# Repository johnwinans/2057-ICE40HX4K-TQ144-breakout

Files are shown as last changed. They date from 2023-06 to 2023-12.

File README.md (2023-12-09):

# 2057-ICE40HX4K-TQ144-breakout
Minimal Raspberry PI breakout board for ICE40HX4K FPGA

Rev 3.0 has been built!
All features except for the SD card have been tested and are working properly. (Stay tuned for SD card test results).

Example test programs can be found in the [verilog](./verilog) directory.

The BOM (Bill Of Materials) can be found in [2057-ICE40HX4K-TQ144-breakout.md](./2057-ICE40HX4K-TQ144-breakout.md).

## See The Following Repos For Installing Development Tools and Example Code

- [YouTube Playlist](https://www.youtube.com/playlist?list=PL3by7evD3F52On-ws9pcdQuEL-rYbNNFB) discussing Verilog & using this breakout board
- [Raspberry PI Setup](https://github.com/johnwinans/raspberry-pi-install)
- [Icarus Setup & Example Programs](https://github.com/johnwinans/IceStick-Examples-Icarus) (For simulation and debugging)
- [More Example Programs](https://github.com/johnwinans/Verilog-Examples) (More example programs)

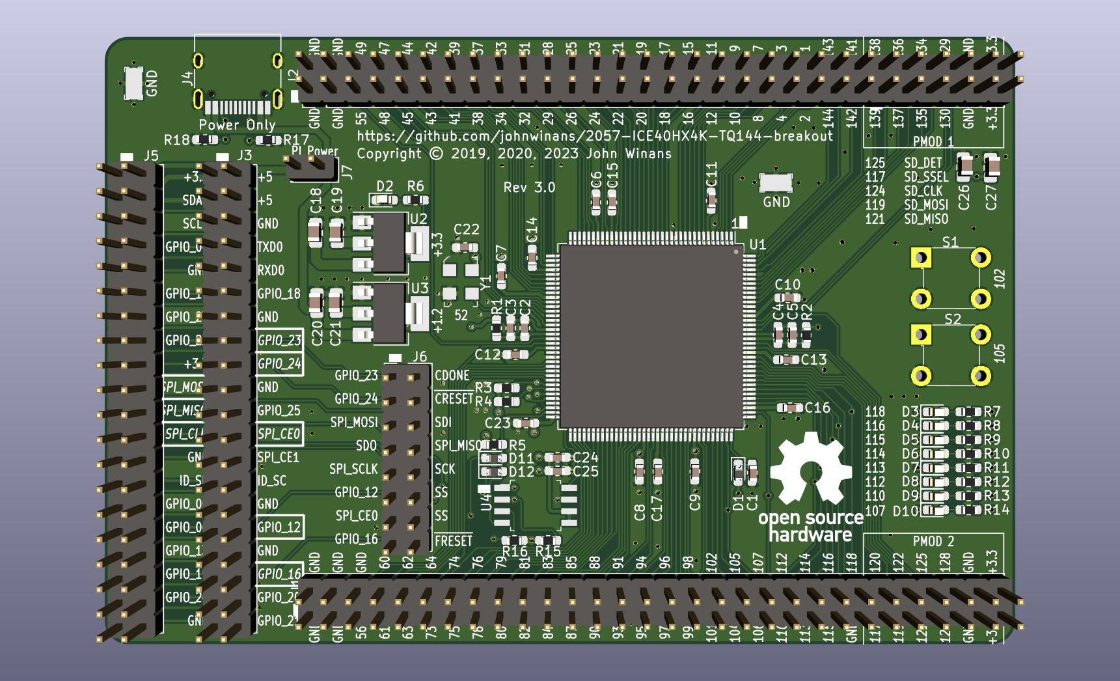
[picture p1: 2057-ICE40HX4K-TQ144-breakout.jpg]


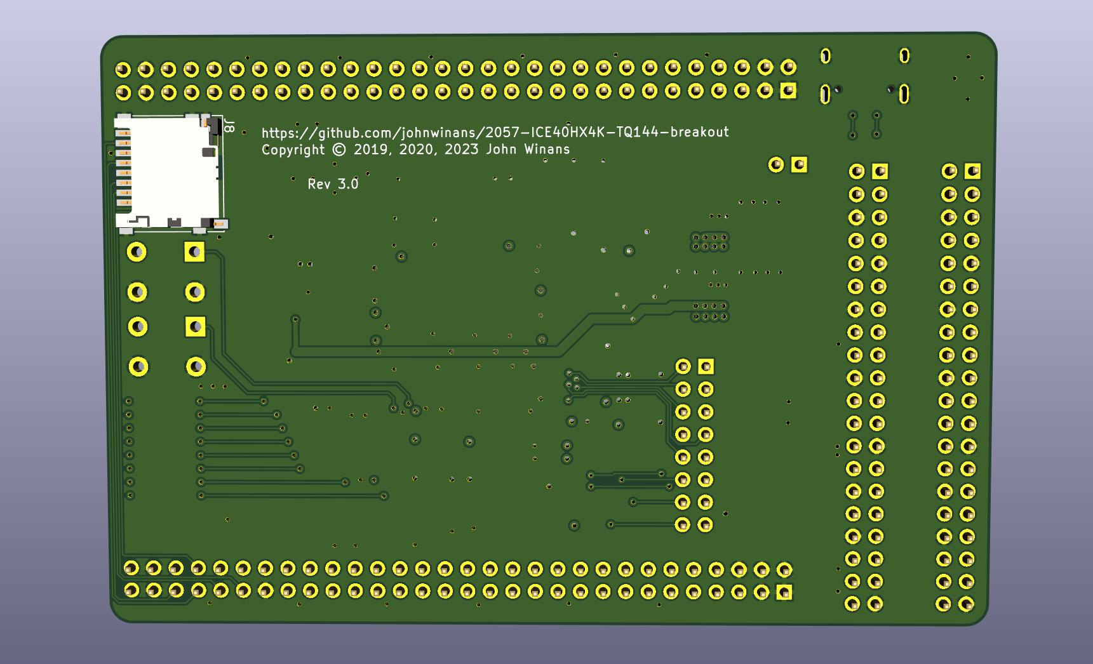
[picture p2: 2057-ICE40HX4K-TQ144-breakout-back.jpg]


# iCE40 Docs

Family page:

- iCE40 Family [page](https://www.latticesemi.com/iCE40)

Direct links to my favorite documents:

- iCE40 LP/HX Datasheet [pdf](https://www.latticesemi.com/view_document?document_id=49312)
- iCE40 Programming and Configuration Techincal Note TN1248 [pdf](https://www.latticesemi.com/view_document?document_id=46502)
- iCE40 sysCLOCK PLL Design and User Guide [pdf](https://www.latticesemi.com/view_document?document_id=47778)
- Memory Usage Guide for iCE40 Devices [pdf](https://www.latticesemi.com/view_document?document_id=47775)
- It looks like updated versions of various manuals appear here: https://www.latticesemi.com/Products/FPGAandCPLD/iCE40

# Release Notes

## Rev 1.1
- Board has been tested and is working properly.

## Rev 2.0
- Added a boot FLASH
- Added SD card

## Rev 3.0
- Change to use USB C connector for power
- Change SD card signals to connect to J1 (instead of J2)
- Change push buttons to use J1 (instead of J2)

# Alternate Parts

Substitutions for U4 (the FLASH chip) include:
- Digikey #1265-1035-1-ND AT45DB161E-SHD-T
- Digikey #1265-1041-1-ND AT45DB161E-SHD2B-T

If you substitute the FLASH then see the comments regarding setting the total number of bytes to program circa line 150 in: [verilog/prog-flash.sh](verilog/prog-flash.sh)

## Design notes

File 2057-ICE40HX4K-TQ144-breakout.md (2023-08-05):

# 2057-ICE40HX4K-TQ144-breakout.sch

## Sat Aug  5 02:54:05 2023

## Eeschema 5.1.5+dfsg1-2build2

## Component Count:73

Ref | Qty | Value | Digikey | Datasheet | Description
----|-----|-------|---------|-----------|------------
C1, C2, C4, C6, C7, C8, C9, C10, C11, C12, C13, C14, C15, C16, C17, C22, C23, C24 | 18 | .1uF | 445-1314-1-ND | https://product.tdk.com/system/files/dam/doc/product/capacitor/ceramic/mlcc/catalog/mlcc_commercial_general_en.pdf | Unpolarized capacitor
C3, C5 | 2 | 10uF | 1276-1119-1-ND | https://media.digikey.com/pdf/Data%20Sheets/Samsung%20PDFs/CL10A106MQ8NNNC_Spec.pdf | Unpolarized capacitor
C18, C20 | 2 | 10uF | 1276-1119-1-ND | https://media.digikey.com/pdf/Data%20Sheets/Samsung%20PDFs/CL10A106MQ8NNNC_Spec.pdf | Unpolarized capacitor
C19, C21, C27 | 3 | 22uF | 1276-2868-1-ND | https://media.digikey.com/pdf/Data%20Sheets/Samsung%20PDFs/CL10A226MQ8NRNE_Spec.pdf | Unpolarized capacitor, small symbol
C25 | 1 | 4.7uF | 1276-1045-1-ND | https://media.digikey.com/pdf/Data%20Sheets/Samsung%20PDFs/CL10A475KQ8NNNC_Spec.pdf | Unpolarized capacitor
C26 | 1 | .1uF | 445-1314-1-ND | https://product.tdk.com/system/files/dam/doc/product/capacitor/ceramic/mlcc/catalog/mlcc_commercial_general_en.pdf | Unpolarized capacitor, small symbol
D1, D11, D12 | 3 | 1N4448WSF-7 | 1N4448WSF-7DICT-ND | https://www.diodes.com/assets/Datasheets/1N4448WSF.pdf | Diode, filled shape
D2, D3, D4, D5, D6, D7, D8, D9, D10 | 9 | LED_ALT | B1911PG--20D000514U1930 | https://media.digikey.com/pdf/Data%20Sheets/Harvatek%20PDFs/B1911PG--20D000514U1930.pdf | Light emitting diode, filled shape
J1, J2 | 2 | Conn_02x30_Odd_Even | S2011EC-30-ND | https://drawings-pdf.s3.amazonaws.com/11636.pdf | Generic connector, double row, 02x30, odd/even pin numbering scheme (row 1 odd numbers, row 2 even numbers), script generated (kicad-library-utils/schlib/autogen/connector/)
J3, J5 | 2 | RaspberryPI-B+header | S2011EC-20-ND | https://drawings-pdf.s3.amazonaws.com/11636.pdf | Raspberry PI J8 GPIO header
J4 | 1 | USB4105-GF-A | 2073-USB4105-GF-ATR-ND | https://media.digikey.com/pdf/Data%20Sheets/GCT%20PDFs/USB4105%20-%20Product%20Drawing.pdf | CONN RCP USB2.0 TYP C 24P SMD RA
J6 | 1 | Conn_02x08_Odd_Even | 10129381-916001BLF-ND | https://cdn.amphenol-cs.com/media/wysiwyg/files/drawing/10129381.pdf | Generic connector, double row, 02x08, odd/even pin numbering scheme (row 1 odd numbers, row 2 even numbers), script generated (kicad-library-utils/schlib/autogen/connector/)
J7 | 1 | Conn_02x01 | 2057-PH1-02-UA-ND | https://app.adam-tech.com/products/download/data_sheet/201605/ph1-xx-ua-data-sheet.pdf | Generic connector, double row, 02x01, this symbol is compatible with counter-clockwise, top-bottom and odd-even numbering schemes., script generated (kicad-library-utils/schlib/autogen/connector/)
J8 | 1 | Micro_SD_Card_Det | HR1941CT-ND | https://www.hirose.com/product/document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 | Micro SD Card Socket with card detection pins
LOGO1 | 1 | Logo_Open_Hardware_Small |  | ~ | Open Hardware logo, small
R1, R2 | 2 | 100 | 311-100HRCT-ND | https://www.yageo.com/upload/media/product/productsearch/datasheet/rchip/PYu-RC_Group_51_RoHS_L_12.pdf | Resistor
R3, R4, R5, R15, R16 | 5 | 10K | 311-10.0KHRCT-ND | https://www.yageo.com/upload/media/product/productsearch/datasheet/rchip/PYu-RC_Group_51_RoHS_L_12.pdf | Resistor
R6, R7, R8, R9, R10, R11, R12, R13, R14 | 9 | 330 | 311-330HRCT-ND | https://www.yageo.com/upload/media/product/productsearch/datasheet/rchip/PYu-RC_Group_51_RoHS_L_12.pdf | Resistor
R17, R18 | 2 | 5.1K | CR0603-FX-5101ELFCT-ND | https://www.bourns.com/docs/product-datasheets/cr.pdf?sfvrsn=574d41f6_14 | Resistor
S1, S2 | 2 | 1825910-6 | 450-1650-ND | https://www.te.com/commerce/DocumentDelivery/DDEController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 | SWITCH TACTILE SPST-NO 0.05A 24V
U1 | 1 | ICE40HX4K-TQ144 | 220-1572-ND | http://www.latticesemi.com/Products/FPGAandCPLD/iCE40 | iCE40 HX FPGA, 3520 LUTs, 1.2V, TQFP-144
U2 | 1 | AZ1117CH-3.3TRG1 | AZ1117CH-3.3TRG1DICT-ND | https://www.diodes.com/assets/Datasheets/AZ1117.pdf | 1A 20V Fixed LDO Linear Regulator, 3.3V, SOT-89/SOT-223/TO-220/TO-252/TO-263
U3 | 1 | AZ1117CH-1.2 | AZ1117CH-1.2TRG1DICT-ND | https://www.diodes.com/assets/Datasheets/AZ1117.pdf | 1A 20V Fixed LDO Linear Regulator, 3.3V, SOT-89/SOT-223/TO-220/TO-252/TO-263
U4 | 1 | AT45DB081E | 1265-1092-1-ND | https://www.renesas.com/us/en/document/dst/at45db081e-datasheet?language=en | 
Y1 | 1 | XLH536025_000000I | 631-1156-1-ND | https://www.idt.com/document/dst/xl-family-low-phase-noise-quartz-based-pll-oscillators-datasheet | XTAL OSC XO 25.0000MHZ HCMOS SMD

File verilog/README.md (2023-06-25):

# Test Apps

These instructions have been verified on:
- Ubuntu 20.04.2 LTS 2023-06-24
- Raspbian GNU/Linux 11 (bullseye) 2023-06-24

# Install the tools

	sudo apt install fpga-icestorm
	sudo apt install arachne-pnr
	sudo apt install iverilog
	sudo apt install gtkwave

Note that on newer systems, the following may be preferred over `arachne-pnr`.  However, it 
may not be in the standard set of available packages.

	sudo apt install nextpnr-ice40

The make files in this project are configured to use arachne-pnr because, at the time of testing, nextpnr-ice40 was not a standard package on th Raspberry PI (that was used as the FLASH programmer.)

# To run these applications on the `2057-ICE40HX4K-TQ144-breakout`

Plug your Raspberry PI into your board and run the following from this cloned repo:

	git clone https://github.com/johnwinans/2057-ICE40HX4K-TQ144-breakout.git
	cd 2057-ICE40HX4K-TQ144-breakout/verilog/blinky
	make
	make flash

# To build and run icarus to simulate this project and view a waveform of the application

	make plot

In gtkwave, open (double-click) the 'tb' object in the tree, click on 'uut'. 

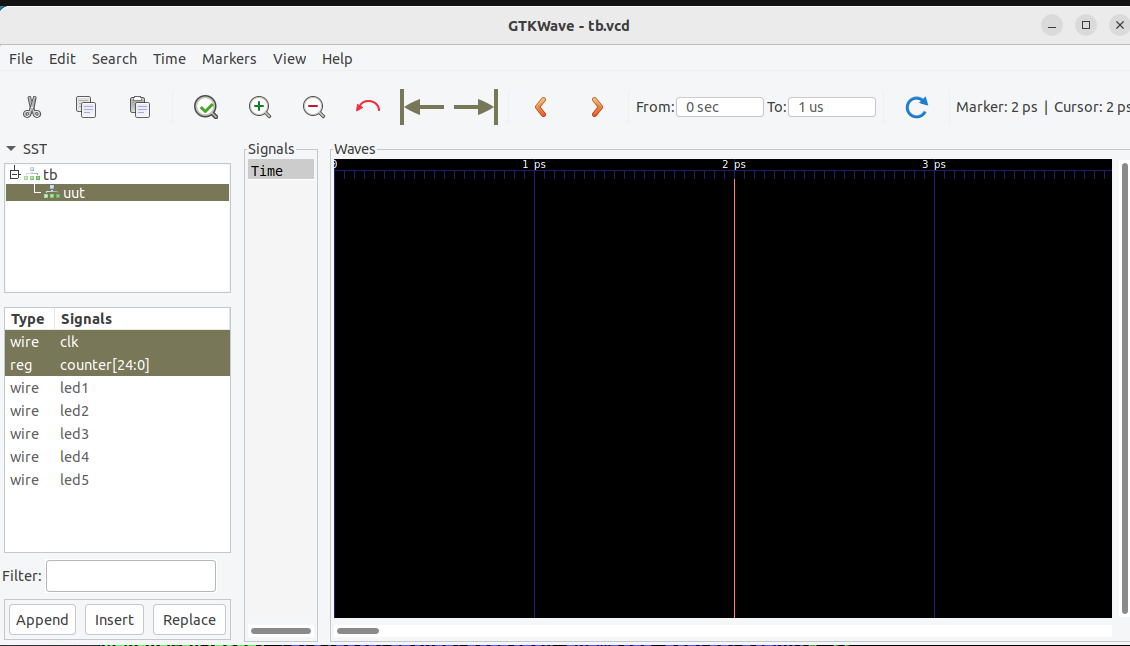
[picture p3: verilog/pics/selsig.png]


Then, in the signals box below click on the 'clk' signal and ctrl-click on 'counter[24:0]'
(so that they are both selected at the same time) and click the Append button at the 
bottom left.  

At this point, you can zoom and scroll around the waveform on the right to see the 
clock signal ticking and the counter advancing on the rising/positive edge of 
the 'clk' signal.

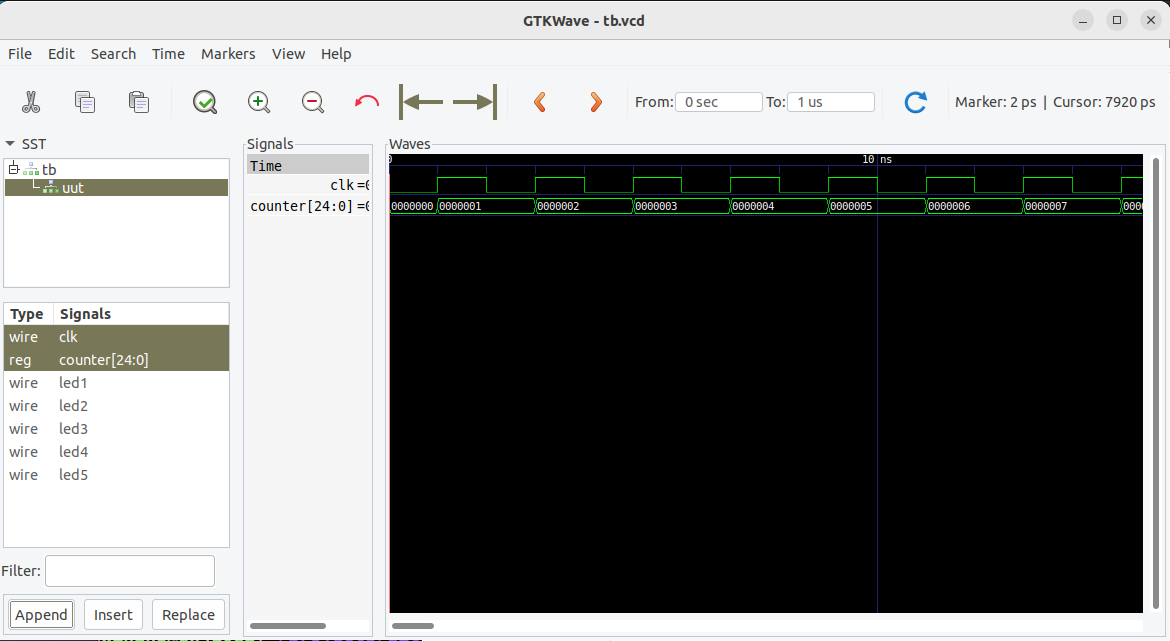
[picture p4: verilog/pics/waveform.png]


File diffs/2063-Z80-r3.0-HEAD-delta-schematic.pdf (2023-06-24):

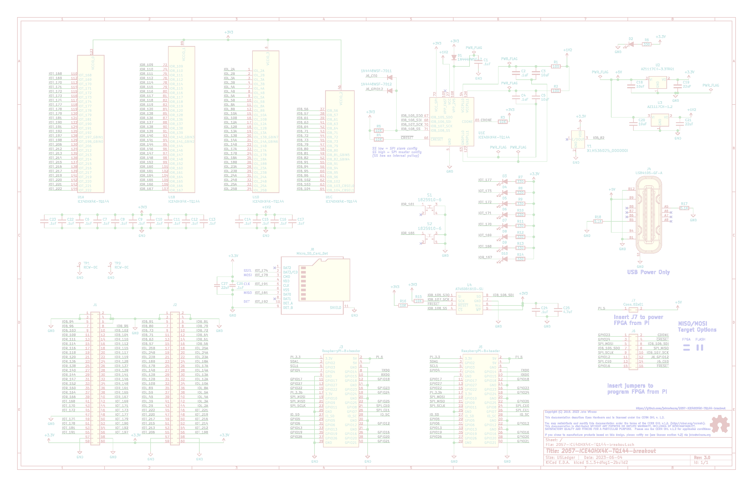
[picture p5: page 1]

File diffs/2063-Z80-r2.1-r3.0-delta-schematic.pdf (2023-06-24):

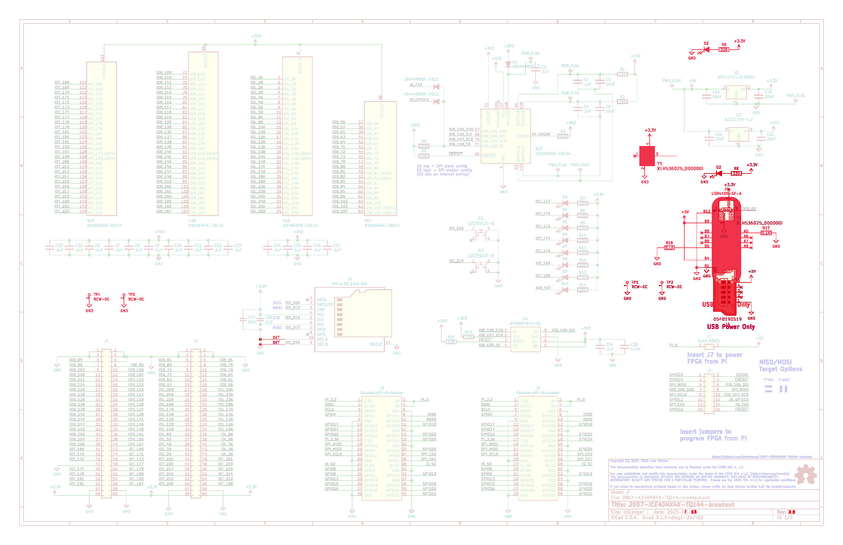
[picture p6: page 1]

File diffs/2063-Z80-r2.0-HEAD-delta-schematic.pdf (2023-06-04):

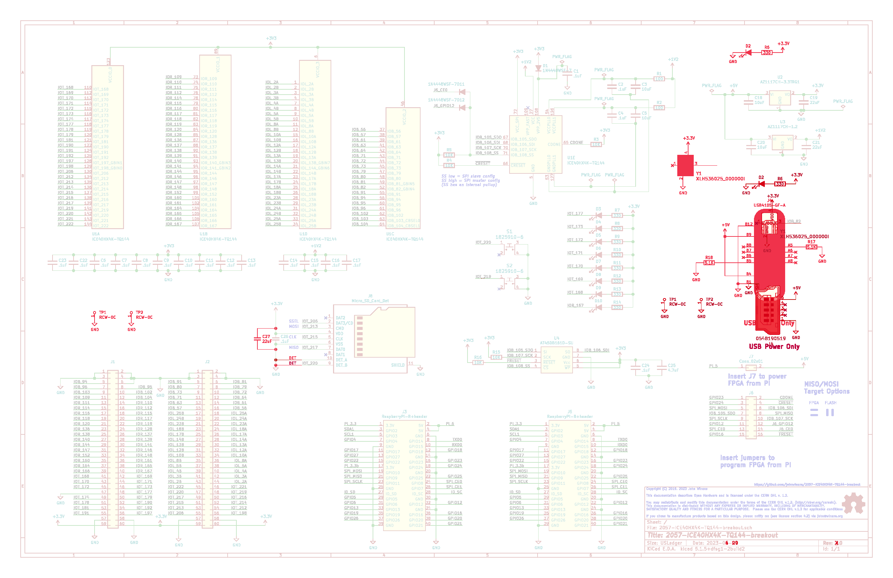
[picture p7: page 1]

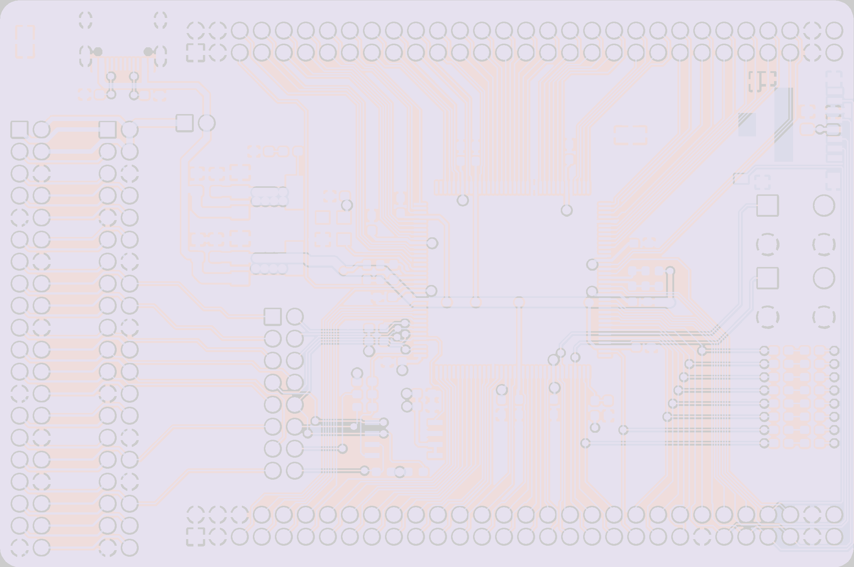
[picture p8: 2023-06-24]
diffs/2063-Z80-r3.0-HEAD-delta-pcb.png

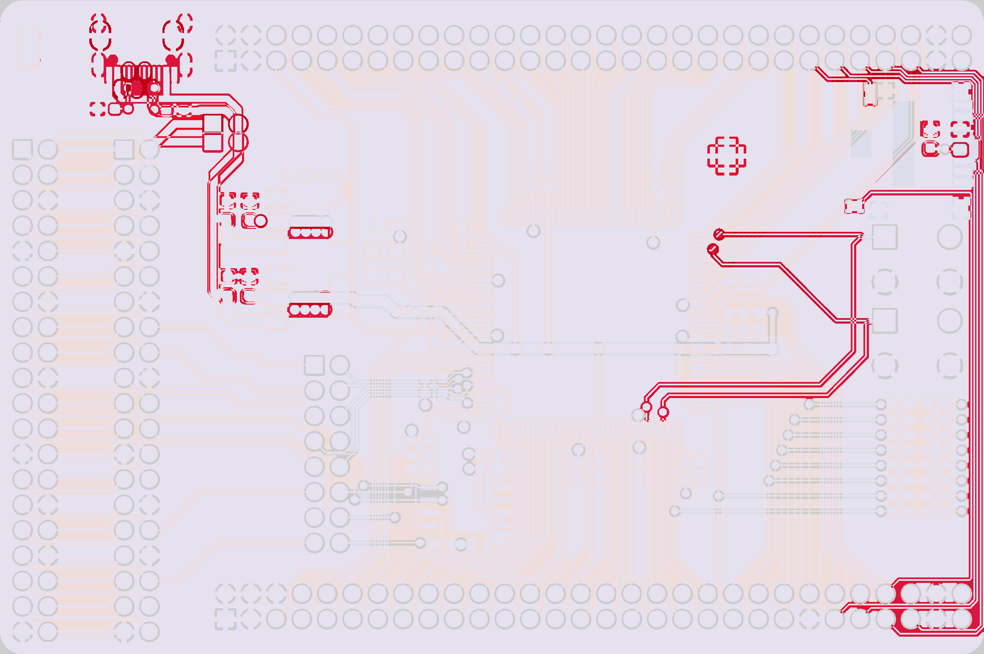
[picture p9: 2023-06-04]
diffs/2063-Z80-r2.0-HEAD-delta-pcb.png

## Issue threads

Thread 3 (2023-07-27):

Reset on the 2057-ICE40HX4K-TQ144-breakout board.

dennowiggle, 2023-07-27:
On power-up reset follows exactly 3.3V. I tried to add a delay to reset by adding :
1. A 10uF cap across S1.1 to S1.3
2. A 1N914 diode from S1.1 to 3.3V so that the cap discharges with 3.3V
3. A 1K bleed resistor across 3.3V and GND..

The power-on-reset delay looks improved but on power down the FPGA still outputs a signal until VCC reaches 1.2V when I tested with a clock output on one of the pins.

It would be helpful to have a reset supervisor IC on the 2057-ICE40HX4K-TQ144 board. An example part is Digikey part number MCP120-300HI/TO-ND.

dennowiggle, 2023-07-27:
The power up waveform with the rework:
Green = 3.3V
Purple = reset signal to FPGA
Yellow = FPGA Output
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
This is the power down followed by power up waveform.
Green = 3.3V
Purple = reset signal to FPGA  (with the rework)
Yellow = clock output active to ~1.13V
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

dennowiggle, 2023-07-27:
I didn't mention above but the reason for being interested in a reset supervisor is to prevent corruption to the SD card and to prevent the CPU on 2067 from mis-behaving. Maybe a better place for a reset supervisor is on the NMI interrupt going to the CPU, and then put code in place to gracefully stop the CPU while there is enough power. Let the FPGA go as long as it can. Thoughts?

EtchedPixels, 2023-07-27:
Don't see why it matters for the SD immediately. What kind of SD corruption are you worried about, if it's mid transaction it should just drop the write, and if it's end of transaction then you can be tens of milliseconds doing the write and with a high current draw so a little reset controller won't make any difference ?

johnwinans, 2023-07-27:
I'm not seeing the urgency either.  I expect to use the FPGA's internal reset logic to reset itself that will then control the reset signals on the CPU and other things.

I have yet to fully consider all the issues though.  It could glitch.

johnwinans, 2023-12-07:
I am going to leave this issue open until I get to the design of a single-board FPGA + CPU project.   I will add a reset supervisor at that time to the new project and probably also spin this project too as some other non-critical issues have have cropped up.  I see no reason not to add one to this too for optional population.

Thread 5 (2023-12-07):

Move the FPGA oscillator clock connection from pin 52 to pin 49

johnwinans, 2023-12-07:
Using 52 for the oscillator is not optimal.
Can not use a PLL_PAD unless the clock is on pin 49.
If use a PLL_CORE with a wire from pin 52 as the reference clock then pin 49 is forced to be an output only.

The work-around is to use a CORE and only use pin 49 as an output.

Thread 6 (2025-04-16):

Add more ground test points

johnwinans, 2025-04-16:
Add more ground test points
Add a thru-hole to the surface-mount pads so can use either a SMT metal-box or a thru-hole test-point with a loop on it like one of these:
https://www.digikey.com/en/products/detail/keystone-electronics/5261/12751714
https://www.digikey.com/en/products/detail/keystone-electronics/5282/12751666
https://www.digikey.com/en/products/detail/keystone-electronics/5287/12751678

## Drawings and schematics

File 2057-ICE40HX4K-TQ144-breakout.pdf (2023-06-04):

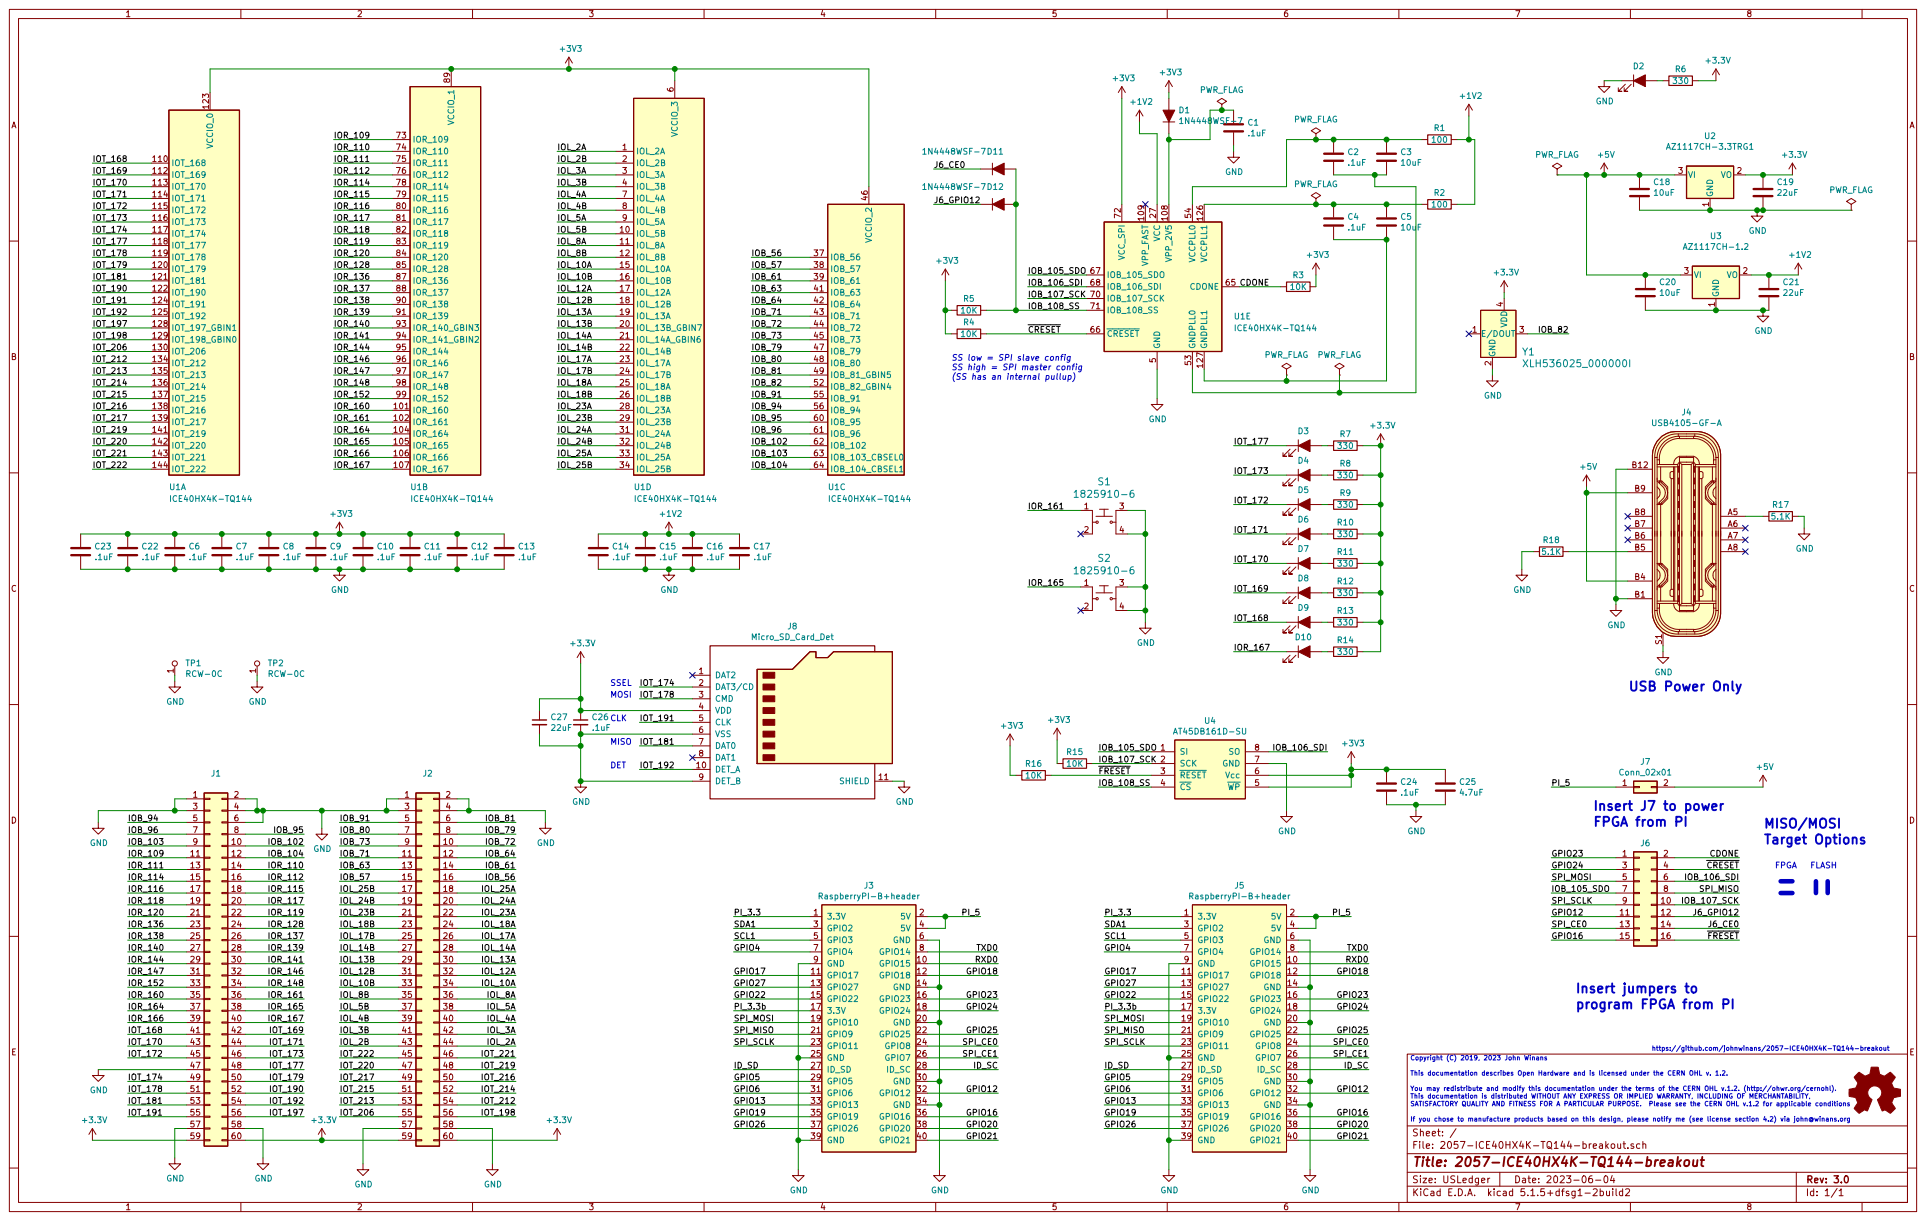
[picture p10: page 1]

SS low = SPI slave config
SS high = SPI master config
(SS has an internal pullup)

FPGA from PI DET SSEL CLK MISO MOSI

If you chose to manufacture products based on this design, please notify me (see license section 4.2) via john@winans.org https://github.com/johnwinans/2057-ICE40HX4K-TQ144-breakout USB Power Only

E Date: 2023-06-04 KiCad E.D.A. kicad 5.1.5+dfsg1-2build2
Copyright (C) 2019, 2023 John Winans This documentation describes Open Hardware and is licensed under the CERN OHL v. 1.2. You may redistribute and modify this documentation under the terms of the CERN OHL v.1.2. (http://ohwr.org/cernohl). This documentation is distributed WITHOUT ANY EXPRESS OR IMPLIED WARRANTY, INCLUDING OF MERCHANTABILITY, SATISFACTORY QUALITY AND FITNESS FOR A PARTICULAR PURPOSE. Please see the CERN OHL v.1.2 for applicable conditions

File: 2057-ICE40HX4K-TQ144-breakout.sch Sheet: /
Id: 1/1 Title: 2057-ICE40HX4K-TQ144-breakout

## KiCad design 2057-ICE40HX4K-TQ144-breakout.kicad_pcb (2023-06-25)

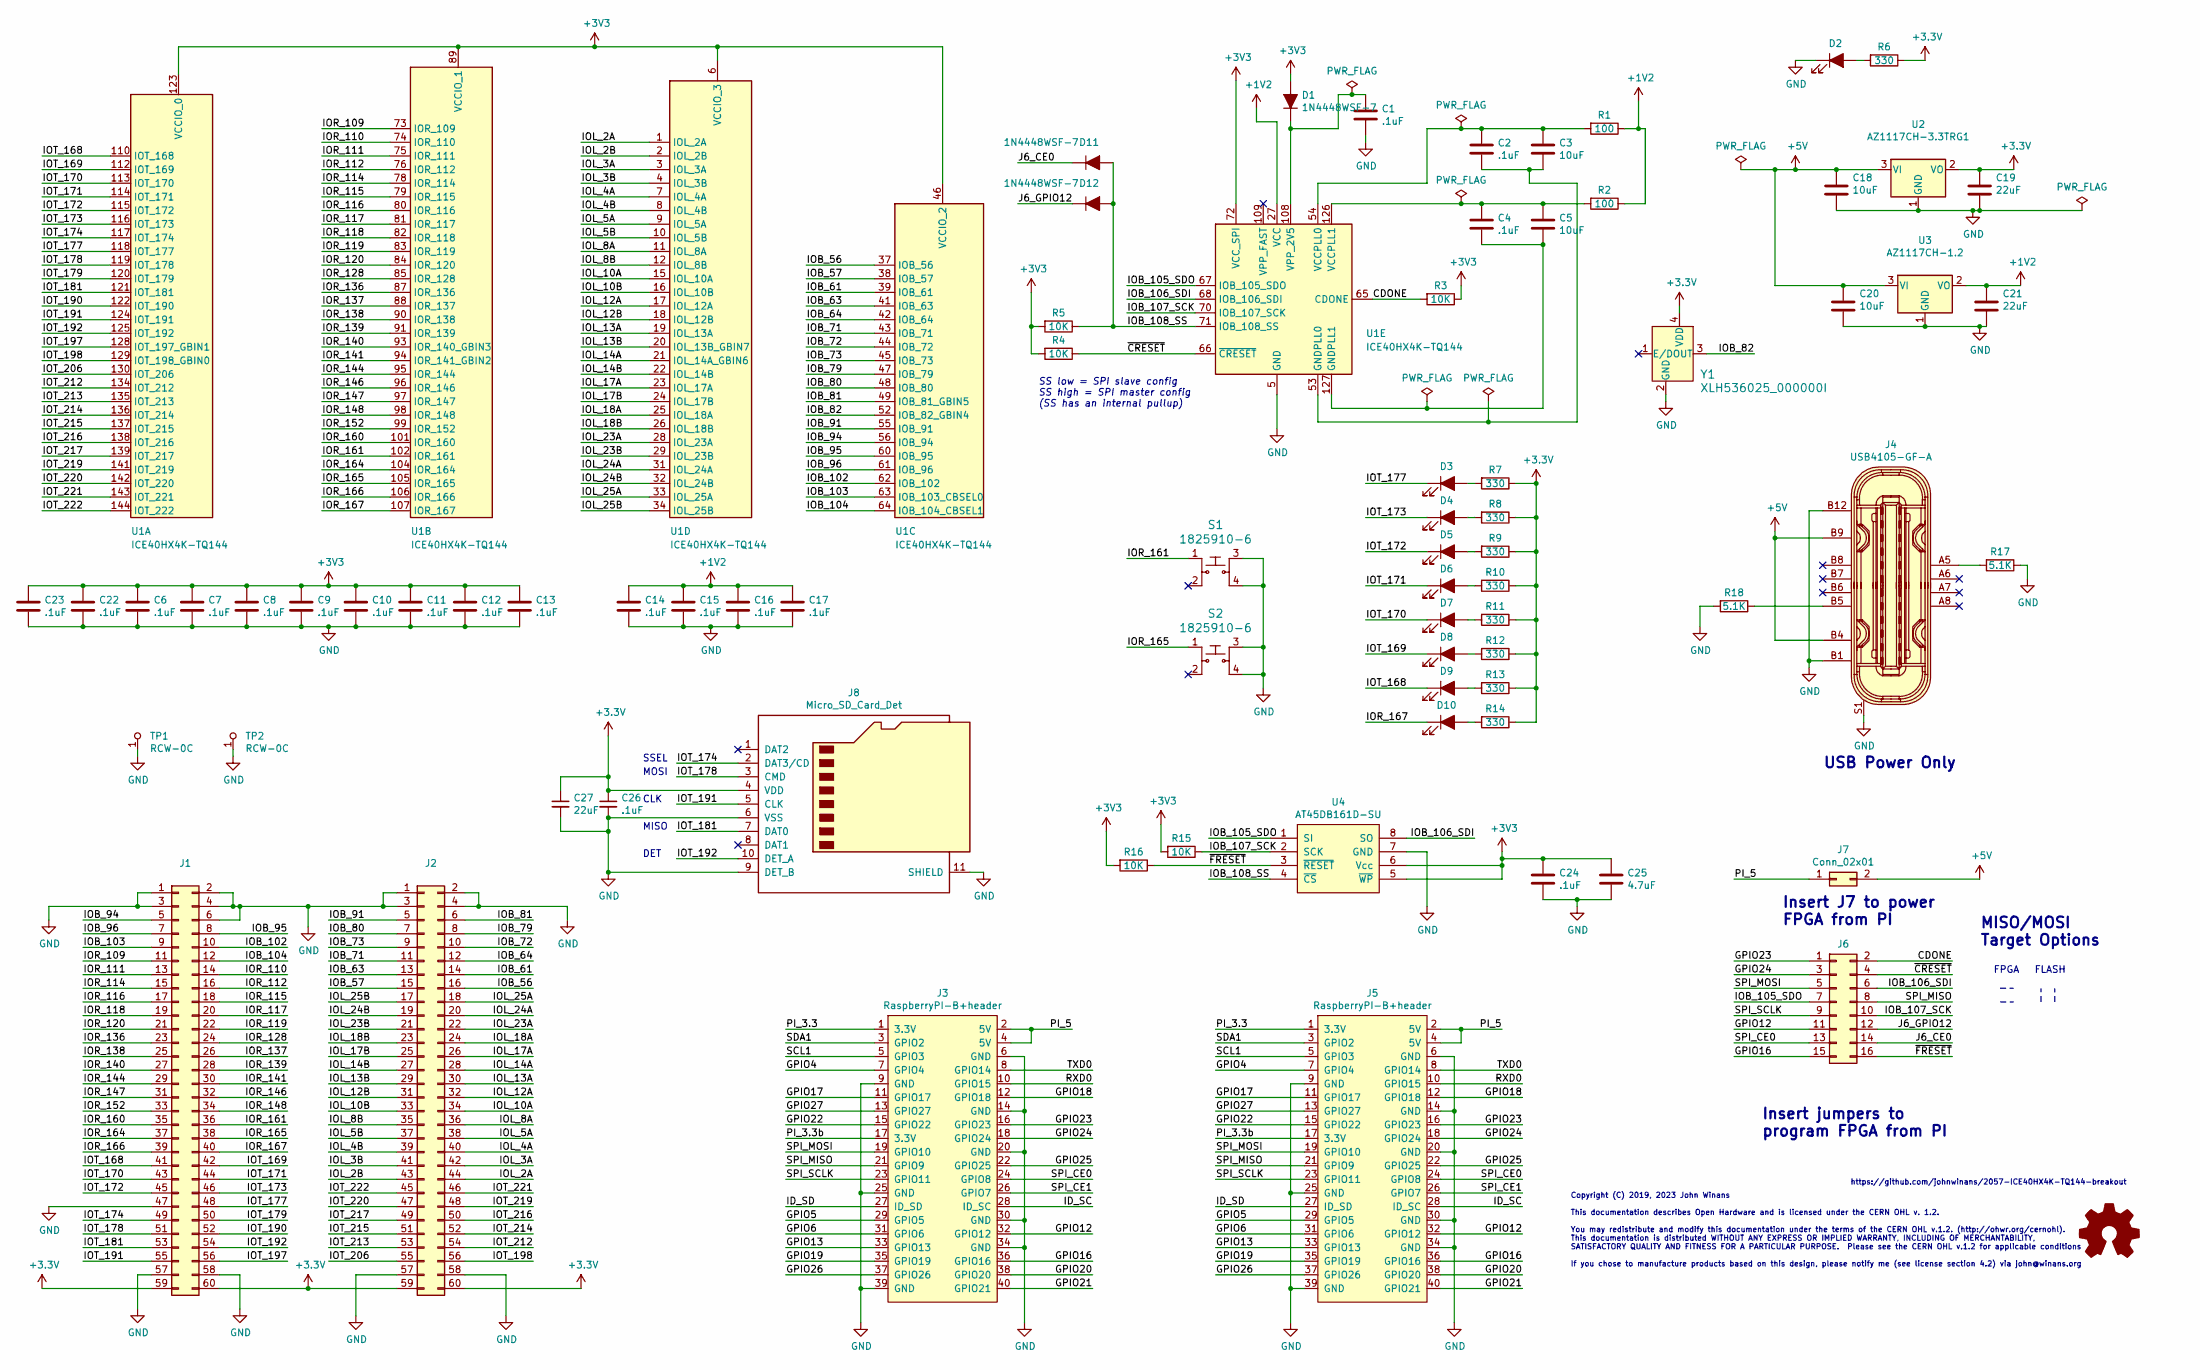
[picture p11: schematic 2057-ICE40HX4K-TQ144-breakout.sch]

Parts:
C1, C2, C4, C6, C7, C8, C9, C10, C11, C12, C13, C14, C15, C16, C17, C22, C23, C24: .1uF; C_0603_1608Metric_Pad1.05x0.95mm_HandSolder; MPN C1608X7R1H104K080AA; Digi-Key_PN 445-1314-1-ND
C3, C5: 10uF; C_0603_1608Metric_Pad1.05x0.95mm_HandSolder; MPN CL10A106MQ8NNNC; Digi-Key_PN 1276-1119-1-ND
C18, C20: 10uF; C_0805_2012Metric_Pad1.15x1.40mm_HandSolder; MPN CL10A106MQ8NNNC; Digi-Key_PN 1276-1119-1-ND
C19, C21, C27: 22uF; C_0805_2012Metric_Pad1.15x1.40mm_HandSolder; MPN CL10A226MQ8NRNE; Digi-Key_PN 1276-2868-1-ND
C25: 4.7uF; C_0603_1608Metric_Pad1.05x0.95mm_HandSolder
C26: .1uF; C_0805_2012Metric_Pad1.15x1.40mm_HandSolder
D1, D11, D12: 1N4448WSF-7; D_0603_1608Metric_Pad1.05x0.95mm_HandSolder; MPN 1N4448WSF-7; Digi-Key_PN 1N4448WSF-7DICT-ND
D2, D3, D4, D5, D6, D7, D8, D9, D10: LED_ALT; LED_0603_1608Metric_Pad1.05x0.95mm_HandSolder; MPN B1911PG--20D000514U1930; Digi-Key_PN B1911PG--20D000514U1930
J1, J2: Conn_02x30_Odd_Even; PinHeader_2x30_P2.54mm_Vertical
J3, J5: RaspberryPI-B+header; PinHeader_2x20_P2.54mm_Vertical
J4: USB4105-GF-A; USB_C_Receptacle_HRO_TYPE-C-31-M-12; MPN USB4105-GF-A; Digi-Key_PN 2073-USB4105-GF-ATR-ND
J6: Conn_02x08_Odd_Even; PinHeader_2x08_P2.54mm_Vertical
J7: Conn_02x01; PinHeader_2x01_P2.54mm_Vertical
J8: Micro_SD_Card_Det; microSD_HC_Hirose_DM3D-SF-bigpad
LOGO1: Logo_Open_Hardware_Small; OSHW-Logo_11.4x12mm_SilkScreen
R1, R2: 100; R_0603_1608Metric_Pad1.05x0.95mm_HandSolder
R3, R4, R5, R15, R16: 10K; R_0603_1608Metric_Pad1.05x0.95mm_HandSolder
R6, R7, R8, R9, R10, R11, R12, R13, R14: 330; R_0603_1608Metric_Pad1.05x0.95mm_HandSolder
R17, R18: 5.1K; R_0603_1608Metric_Pad1.05x0.95mm_HandSolder
S1, S2: 1825910-6; Switch_Tactile_THT_6x6mm; MPN 1825910-6; Digi-Key_PN 450-1650-ND
TP1, TP2: RCW-0C; PROBE_PAD_1206; MPN RCW-0C; Digi-Key_PN A106146CT-ND
U1: ICE40HX4K-TQ144; TQFP-144_20x20mm_P0.5mm; MPN ICE40HX4K-TQ144; Digi-Key_PN 220-1572-ND
U2: AZ1117CH-3.3TRG1; SOT-223-3_TabPin2; MPN AZ1117CH-3.3TRG1; Digi-Key_PN AZ1117CH-3.3TRG1DICT-ND
U3: AZ1117CH-1.2; SOT-223-3_TabPin2; MPN AZ1117CH-1.2TRG1; Digi-Key_PN AZ1117CH-1.2TRG1DICT-ND
U4: AT45DB161D-SU; SOIC-8_W5.6mm
Y1: XLH536025_000000I; Oscillator_XLH536025.000000I; MPN XLH536025.000000I; Digi-Key_PN 631-1156-1-ND

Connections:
+1V2: C14.1, C15.1, C16.1, C17.1, C21.1, R1.1, R2.1, U1.27 (VCC), U1.40 (VCC), U1.92 (VCC), U1.111 (VCC), U3.2 (VO)
+5V: C18.1, C20.1, J4.A4, J4.A9, J4.B4, J4.B9, J7.2, U2.3 (VI), U3.3 (VI)
/CDONE: J6.2, R3.2, U1.65 (CDONE)
/GPIO4: J3.7 (GPIO4), J5.7 (GPIO4)
/GPIO5: J3.29 (GPIO5), J5.29 (GPIO5)
/GPIO6: J3.31 (GPIO6), J5.31 (GPIO6)
/GPIO12: J3.32 (GPIO12), J5.32 (GPIO12), J6.11
/GPIO13: J3.33 (GPIO13), J5.33 (GPIO13)
/GPIO16: J3.36 (GPIO16), J5.36 (GPIO16), J6.15
/GPIO17: J3.11 (GPIO17), J5.11 (GPIO17)
/GPIO18: J3.12 (GPIO18), J5.12 (GPIO18)
/GPIO19: J3.35 (GPIO19), J5.35 (GPIO19)
/GPIO20: J3.38 (GPIO20), J5.38 (GPIO20)
/GPIO21: J3.40 (GPIO21), J5.40 (GPIO21)
/GPIO22: J3.15 (GPIO22), J5.15 (GPIO22)
/GPIO23: J3.16 (GPIO23), J5.16 (GPIO23), J6.1
/GPIO24: J3.18 (GPIO24), J5.18 (GPIO24), J6.3
/GPIO25: J3.22 (GPIO25), J5.22 (GPIO25)
/GPIO26: J3.37 (GPIO26), J5.37 (GPIO26)
/GPIO27: J3.13 (GPIO27), J5.13 (GPIO27)
/ID_SC: J3.28 (ID_SC), J5.28 (ID_SC)
/ID_SD: J3.27 (ID_SD), J5.27 (ID_SD)
/IOB_56: J2.16, U1.37 (IOB_56)
/IOB_57: J2.15, U1.38 (IOB_57)
/IOB_61: J2.14, U1.39 (IOB_61)
/IOB_63: J2.13, U1.41 (IOB_63)
/IOB_64: J2.12, U1.42 (IOB_64)
/IOB_71: J2.11, U1.43 (IOB_71)
/IOB_72: J2.10, U1.44 (IOB_72)
/IOB_73: J2.9, U1.45 (IOB_73)
/IOB_79: J2.8, U1.47 (IOB_79)
/IOB_80: J2.7, U1.48 (IOB_80)
/IOB_81: J2.6, U1.49 (IOB_81_GBIN5)
/IOB_82: U1.52 (IOB_82_GBIN4), Y1.3 (OUT)
/IOB_91: J2.5, U1.55 (IOB_91)
/IOB_94: J1.5, U1.56 (IOB_94)
/IOB_95: J1.8, U1.60 (IOB_95)
/IOB_96: J1.7, U1.61 (IOB_96)
/IOB_102: J1.10, U1.62 (IOB_102)
/IOB_103: J1.9, U1.63 (IOB_103_CBSEL0)
/IOB_104: J1.12, U1.64 (IOB_104_CBSEL1)
/IOB_105_SDO: J6.7, U1.67 (IOB_105_SDO), U4.1 (SI)
/IOB_106_SDI: J6.6, U1.68 (IOB_106_SDI), U4.8 (SO)
/IOB_107_SCK: J6.10, R15.1, U1.70 (IOB_107_SCK), U4.2 (SCK)
/IOB_108_SS: D11.2 (A), D12.2 (A), R5.1, U1.71 (IOB_108_SS), U4.4 (~CS~)
/IOL_2A: J2.44, U1.1 (IOL_2A)
/IOL_2B: J2.43, U1.2 (IOL_2B)
/IOL_3A: J2.42, U1.3 (IOL_3A)
/IOL_3B: J2.41, U1.4 (IOL_3B)
/IOL_4A: J2.40, U1.7 (IOL_4A)
/IOL_4B: J2.39, U1.8 (IOL_4B)
/IOL_5A: J2.38, U1.9 (IOL_5A)
/IOL_5B: J2.37, U1.10 (IOL_5B)
/IOL_8A: J2.36, U1.11 (IOL_8A)
/IOL_8B: J2.35, U1.12 (IOL_8B)
/IOL_10A: J2.34, U1.15 (IOL_10A)
/IOL_10B: J2.33, U1.16 (IOL_10B)
/IOL_12A: J2.32, U1.17 (IOL_12A)
/IOL_12B: J2.31, U1.18 (IOL_12B)
/IOL_13A: J2.30, U1.19 (IOL_13A)
/IOL_13B: J2.29, U1.20 (IOL_13B_GBIN7)
/IOL_14A: J2.28, U1.21 (IOL_14A_GBIN6)
/IOL_14B: J2.27, U1.22 (IOL_14B)
/IOL_17A: J2.26, U1.23 (IOL_17A)
/IOL_17B: J2.25, U1.24 (IOL_17B)
/IOL_18A: J2.24, U1.25 (IOL_18A)
/IOL_18B: J2.23, U1.26 (IOL_18B)
/IOL_23A: J2.22, U1.28 (IOL_23A)
/IOL_23B: J2.21, U1.29 (IOL_23B)
/IOL_24A: J2.20, U1.31 (IOL_24A)
/IOL_24B: J2.19, U1.32 (IOL_24B)
/IOL_25A: J2.18, U1.33 (IOL_25A)
/IOL_25B: J2.17, U1.34 (IOL_25B)
/IOR_109: J1.11, U1.73 (IOR_109)
/IOR_110: J1.14, U1.74 (IOR_110)
/IOR_111: J1.13, U1.75 (IOR_111)
/IOR_112: J1.16, U1.76 (IOR_112)
/IOR_114: J1.15, U1.78 (IOR_114)
/IOR_115: J1.18, U1.79 (IOR_115)
/IOR_116: J1.17, U1.80 (IOR_116)
/IOR_117: J1.20, U1.81 (IOR_117)
/IOR_118: J1.19, U1.82 (IOR_118)
/IOR_119: J1.22, U1.83 (IOR_119)
/IOR_120: J1.21, U1.84 (IOR_120)
/IOR_128: J1.24, U1.85 (IOR_128)
/IOR_136: J1.23, U1.87 (IOR_136)
/IOR_137: J1.26, U1.88 (IOR_137)
/IOR_138: J1.25, U1.90 (IOR_138)
/IOR_139: J1.28, U1.91 (IOR_139)
/IOR_140: J1.27, U1.93 (IOR_140_GBIN3)
/IOR_141: J1.30, U1.94 (IOR_141_GBIN2)
/IOR_144: J1.29, U1.95 (IOR_144)
/IOR_146: J1.32, U1.96 (IOR_146)
/IOR_147: J1.31, U1.97 (IOR_147)
/IOR_148: J1.34, U1.98 (IOR_148)
/IOR_152: J1.33, U1.99 (IOR_152)
/IOR_160: J1.35, U1.101 (IOR_160)
/IOR_161: J1.36, S1.1, U1.102 (IOR_161)
/IOR_164: J1.37, U1.104 (IOR_164)
/IOR_165: J1.38, S2.1, U1.105 (IOR_165)
/IOR_166: J1.39, U1.106 (IOR_166)
/IOR_167: D10.1 (K), J1.40, U1.107 (IOR_167)
/IOT_168: D9.1 (K), J1.41, U1.110 (IOT_168)
/IOT_169: D8.1 (K), J1.42, U1.112 (IOT_169)
/IOT_170: D7.1 (K), J1.43, U1.113 (IOT_170)
/IOT_171: D6.1 (K), J1.44, U1.114 (IOT_171)
/IOT_172: D5.1 (K), J1.45, U1.115 (IOT_172)
/IOT_173: D4.1 (K), J1.46, U1.116 (IOT_173)
/IOT_174: J1.49, J8.2 (DAT3/CD), U1.117 (IOT_174)
/IOT_177: D3.1 (K), J1.48, U1.118 (IOT_177)
/IOT_178: J1.51, J8.3 (CMD), U1.119 (IOT_178)
/IOT_179: J1.50, U1.120 (IOT_179)
/IOT_181: J1.53, J8.7 (DAT0), U1.121 (IOT_181)
/IOT_190: J1.52, U1.122 (IOT_190)
/IOT_191: J1.55, J8.5 (CLK), U1.124 (IOT_191)
/IOT_192: J1.54, J8.10 (DET_A), U1.125 (IOT_192)
/IOT_197: J1.56, U1.128 (IOT_197_GBIN1)
/IOT_198: J2.56, U1.129 (IOT_198_GBIN0)
/IOT_206: J2.55, U1.130 (IOT_206)
/IOT_212: J2.54, U1.134 (IOT_212)
/IOT_213: J2.53, U1.135 (IOT_213)
/IOT_214: J2.52, U1.136 (IOT_214)
/IOT_215: J2.51, U1.137 (IOT_215)
/IOT_216: J2.50, U1.138 (IOT_216)
/IOT_217: J2.49, U1.139 (IOT_217)
/IOT_219: J2.48, U1.141 (IOT_219)
/IOT_220: J2.47, U1.142 (IOT_220)
/IOT_221: J2.46, U1.143 (IOT_221)
/IOT_222: J2.45, U1.144 (IOT_222)
/J6_CE0: D11.1 (K), J6.14
/J6_GPIO12: D12.1 (K), J6.12
/PI_3.3: J3.1 (3.3V), J5.1 (3.3V)
/PI_3.3b: J3.17 (3.3V), J5.17 (3.3V)
/PI_5: J3.2 (5V), J3.4 (5V), J5.2 (5V), J5.4 (5V), J7.1
/RXD0: J3.10 (GPIO15), J5.10 (GPIO15)
/SCL1: J3.5 (GPIO3), J5.5 (GPIO3)
/SDA1: J3.3 (GPIO2), J5.3 (GPIO2)
/SPI_CE0: J3.24 (GPIO8), J5.24 (GPIO8), J6.13
/SPI_CE1: J3.26 (GPIO7), J5.26 (GPIO7)
/SPI_MISO: J3.21 (GPIO9), J5.21 (GPIO9), J6.8
/SPI_MOSI: J3.19 (GPIO10), J5.19 (GPIO10), J6.5
/SPI_SCLK: J3.23 (GPIO11), J5.23 (GPIO11), J6.9
/TXD0: J3.8 (GPIO14), J5.8 (GPIO14)
/~CRESET~: J6.4, R4.1, U1.66 (~CRESET)
/~FRESET~: J6.16, R16.1, U4.3 (~RESET~)
GND: C1.2, C6.2, C7.2, C8.2, C9.2, C10.2, C11.2, C12.2, C13.2, C14.2, C15.2, C16.2, C17.2, C18.2, C19.2, C20.2, C21.2, C22.2, C23.2, C24.2, C25.2, C26.2, C27.2, D2.1 (K), J1.1, J1.2, J1.3, J1.4, J1.6, J1.47, J1.57, J1.58, J2.1, J2.2, J2.3, J2.4, J2.57, J2.58, J3.6 (GND), J3.9 (GND), J3.14 (GND), J3.20 (GND), J3.25 (GND), J3.30 (GND), J3.34 (GND), J3.39 (GND), J4.A1, J4.A12, J4.B1, J4.B12, J4.S1, J5.6 (GND), J5.9 (GND), J5.14 (GND), J5.20 (GND), J5.25 (GND), J5.30 (GND), J5.34 (GND), J5.39 (GND), J8.6 (VSS), J8.9 (DET_B), J8.11 (SHIELD), R17.1, R18.2, S1.3, S1.4, S2.3, S2.4, TP1.1, TP2.1, U1.5 (GND), U1.13 (GND), U1.14 (GND), U1.59 (GND), U1.69 (GND), U1.86 (GND), U1.103 (GND), U1.132 (GND), U1.140 (GND), U2.1 (GND), U3.1 (GND), U4.7 (GND), Y1.2 (GND)
unnamed: C1.1, D1.1 (K), U1.108 (VPP_2V5)
unnamed: C2.1, C3.1, R1.2, U1.54 (VCCPLL0)
unnamed: C2.2, C3.2, U1.53 (GNDPLL0)
unnamed: C4.1, C5.1, R2.2, U1.126 (VCCPLL1)
unnamed: C4.2, C5.2, U1.127 (GNDPLL1)
unnamed: D2.2 (A), R6.2
unnamed: D3.2 (A), R7.2
unnamed: D4.2 (A), R8.2
unnamed: D5.2 (A), R9.2
unnamed: D6.2 (A), R10.2
unnamed: D7.2 (A), R11.2
unnamed: D8.2 (A), R12.2
unnamed: D9.2 (A), R13.2
unnamed: D10.2 (A), R14.2
unnamed: J4.A5, R17.2
unnamed: J4.B5, R18.1

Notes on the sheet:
Copyright (C) 2019, 2023 John Winans This documentation describes Open Hardware and is licensed under the CERN OHL v. 1.2. You may redistribute and modify this documentation under the terms of the CERN OHL v.1.2. (http://ohwr.org/cernohl). This documentation is distributed WITHOUT ANY EXPRESS OR IM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
https://github.com/johnwinans/2057-ICE40HX4K-TQ144-breakout
USB Power Only
Insert J7 to power FPGA from PI
Insert jumpers to program FPGA from PI
SS low = SPI slave config SS high = SPI master config (SS has an internal pullup)
FPGA
FLASH
MISO/MOSI Target Options
MISO
CLK
MOSI
SSEL
DET

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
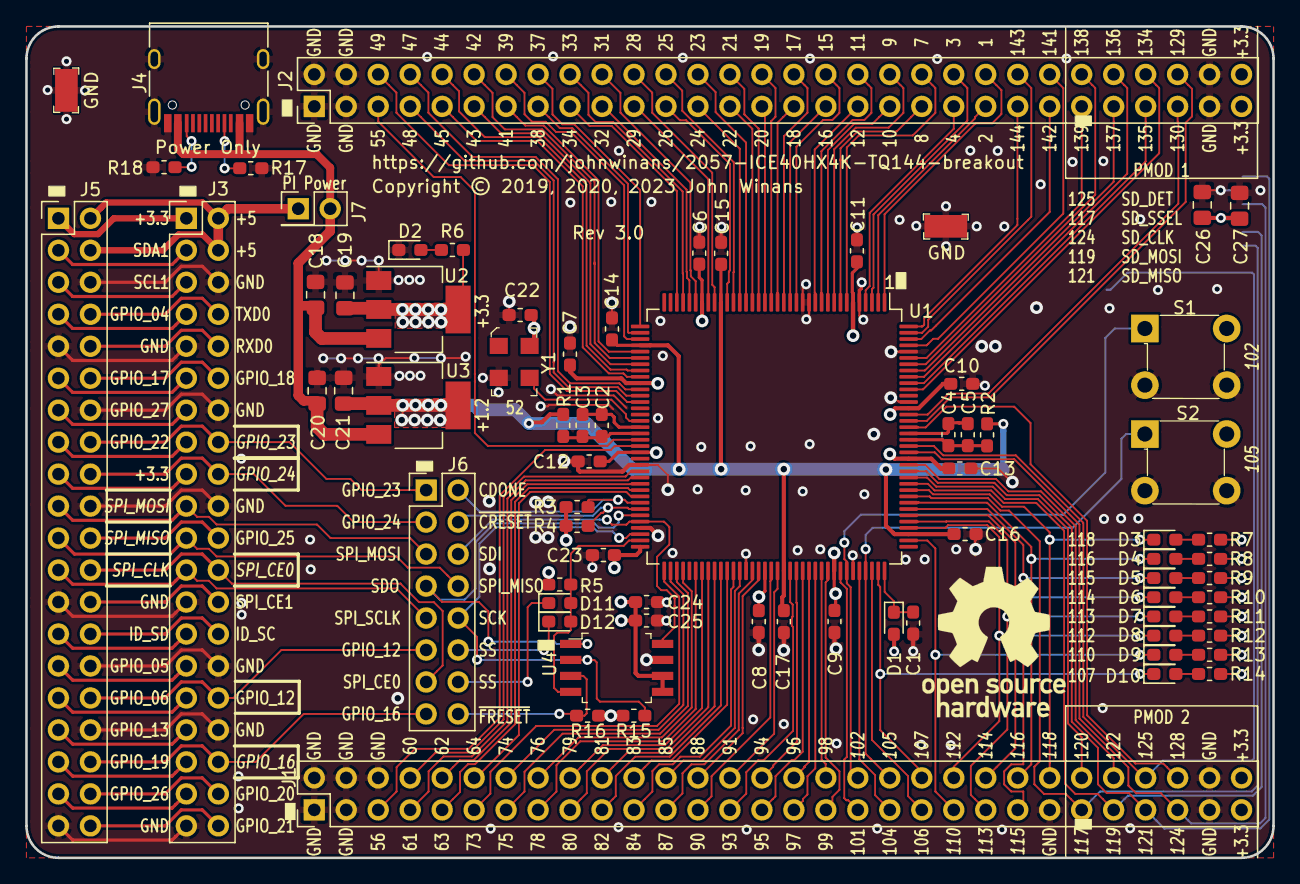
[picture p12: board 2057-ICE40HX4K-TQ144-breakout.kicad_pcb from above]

Board: 4 copper layers, 99.1 x 66.0 mm, 75 parts (1 on the bottom side), 163 nets.

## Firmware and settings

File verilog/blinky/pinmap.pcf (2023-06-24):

# For 2057-ICE40HX4K-TQ144-breakout Rev 3.0
set_io --warn-no-port led1 118
set_io --warn-no-port led2 116
set_io --warn-no-port led3 115
set_io --warn-no-port led4 114
set_io --warn-no-port led5 113
set_io --warn-no-port clk 52

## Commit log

2019-12-31 Candidate release 1.0
    [2057-ICE40HX4K-TQ144-breakout-B_Cu.gbl, 2057-ICE40HX4K-TQ144-breakout-B_Mask.gbs, 2057-ICE40HX4K-TQ144-breakout-B_Paste.gbp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]
2019-12-31 Added some ground vias, schematic PDF & some digikey nos.
    [2057-ICE40HX4K-TQ144-breakout-B_Cu.gbl, 2057-ICE40HX4K-TQ144-breakout-B_Mask.gbs, 2057-ICE40HX4K-TQ144-breakout-B_Paste.gbp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]
2020-01-13 Fix programming headers, add LEDs, cosmetic fixes.
    [2057-ICE40HX4K-TQ144-breakout-B_Cu.gbl, 2057-ICE40HX4K-TQ144-breakout-B_Mask.gbs, 2057-ICE40HX4K-TQ144-breakout-B_Paste.gbp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]
2020-01-13 Added Rev 1.1 gerbers.
    [2057-ICE40HX4K-TQ144-breakout-B_Cu.gbl, 2057-ICE40HX4K-TQ144-breakout-B_Mask.gbs, 2057-ICE40HX4K-TQ144-breakout-B_Paste.gbp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]
2020-01-13 Added two pushbuttons.
    [2057-ICE40HX4K-TQ144-breakout-B_Cu.gbl, 2057-ICE40HX4K-TQ144-breakout-B_Mask.gbs, 2057-ICE40HX4K-TQ144-breakout-B_Paste.gbp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]
2020-01-18 Spec D1 as: 1N4448WSF-7 & label clock on pin 55
    [2057-ICE40HX4K-TQ144-breakout.kicad_pcb, 2057-ICE40HX4K-TQ144-breakout.sch]
2020-06-15 swap ~reset & cdone on silkscreen :-/
    [2057-ICE40HX4K-TQ144-breakout.kicad_pcb]
2023-05-02 Add FLASH, SD, gnd testpoints for Rev 2.0
    [2057-ICE40HX4K-TQ144-breakout-B_Cu.gbl, 2057-ICE40HX4K-TQ144-breakout-B_Mask.gbs, 2057-ICE40HX4K-TQ144-breakout-B_Paste.gbp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]
2023-05-13 Change filter caps to 0805 Silk correct GPIO18 Silk mark GPIO12 Added C27
    [2057-ICE40HX4K-TQ144-breakout-B_Cu.gbl, 2057-ICE40HX4K-TQ144-breakout-B_Mask.gbs, 2057-ICE40HX4K-TQ144-breakout-B_Paste.gbp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]
2023-05-13 Add diff images of PCB and schematic
2023-05-14 Add Digikey info for ordering Diodes and LEDs
    [2057-ICE40HX4K-TQ144-breakout.sch]
2023-05-14 Add a draft of a BOM
2023-05-14 Added .1uF cap part numbers
    [2057-ICE40HX4K-TQ144-breakout.sch]
2023-05-14 Regenerate BOM
2023-06-04 Change USB connector, re-route SD & buttons
    [2057-ICE40HX4K-TQ144-breakout-B_Cu.gbl, 2057-ICE40HX4K-TQ144-breakout-B_Mask.gbs, 2057-ICE40HX4K-TQ144-breakout-B_Paste.gbp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]
2023-06-04 Fix library reference problem
    [2057-ICE40HX4K-TQ144-breakout-B_Cu.gbl, 2057-ICE40HX4K-TQ144-breakout-B_Mask.gbs, 2057-ICE40HX4K-TQ144-breakout-B_Paste.gbp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]
2023-06-24 Freshen gerbers & generate R3 diffs
    [2057-ICE40HX4K-TQ144-breakout-B_Cu.gbl, 2057-ICE40HX4K-TQ144-breakout-B_Mask.gbs, 2057-ICE40HX4K-TQ144-breakout-B_Paste.gbp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]
2023-06-25 Clean up fab layer
    [2057-ICE40HX4K-TQ144-breakout-B_Cu.gbl, 2057-ICE40HX4K-TQ144-breakout-B_Mask.gbs, 2057-ICE40HX4K-TQ144-breakout-B_Paste.gbp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]
2023-06-25 I used arachne for PNR
    note that Arachne is still used because the Raspberry PI does not have a package for nextpnr.
2023-08-05 Update BOM.
    [2057-ICE40HX4K-TQ144-breakout.sch]
2023-12-07 Add notes of alternate FLASH chips
    [2057-ICE40HX4K-TQ144-breakout.sch]
2025-12-28 Switch to using nextpnr-ice40 update prog-flash.sh to deal with PI OS libgpio update in progress

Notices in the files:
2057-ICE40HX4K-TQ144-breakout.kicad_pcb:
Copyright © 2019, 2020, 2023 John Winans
